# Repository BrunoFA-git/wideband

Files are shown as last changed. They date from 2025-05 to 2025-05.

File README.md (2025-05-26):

 

# gerEFI Wideband Controller

[User Documentation](https://gerefi.com/s/wb)

## Building Firmware

The `firmware/boards` directory contains configuration for each board this firmware supports.

For the standalone board and the module built in to gerEFI Hellen boards, `f0_module` is the correct target.  Use the `build_wideband.sh` script to build and package the wideband firmware: both a bin including the bootloader, and a header file consumed by gerEFI that contains no bootloader, to be uploaded over CAN (via the aforementioned bootloader).

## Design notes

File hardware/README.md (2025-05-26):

## `board_module`

Wideband O2 sensor controller on a postage stamp. Contains all the analog and digital control logic to handle a Bosch LSU 4.2, 4.9, or ADV sensor.

Intended to either be mounted on an ECU as a module, or on `board_carrier` to run standalone.

## `board_carrier`

Stacks under `board_module`, has 5v regulator, CAN tranceiver, etc so that the module can exist standlone.

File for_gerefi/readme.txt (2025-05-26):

The file wideband_image.h is generated for use by gerEFI to be able to beam firmware updates to attached wideband controllers.

Use ``cd firmware/boards/f0_module ; ./build_wideband.sh`` to build a fresh version.

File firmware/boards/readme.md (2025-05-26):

Both single-channel and dual-channel F103 boards live at https://github.com/gerefi/gerefi-hardware

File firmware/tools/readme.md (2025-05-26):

* wideband.bin
 initial firmware with botb OpenBLT and current wideband firmware.

* wideband_update.srec
 gerEFI wideband firmware for OpenBLT-via-CAN or OpenBLT-via-uart update methods.

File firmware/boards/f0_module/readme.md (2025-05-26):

Firmware for reference https://github.com/mck1117/wideband/tree/master/board_module F0 hardware.

Also the firmware for https://github.com/BrunoFA-git/hellen-one/tree/master/modules/wbo.

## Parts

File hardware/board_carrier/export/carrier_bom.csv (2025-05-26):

Comment | Designator | Footprint | LCSC
1u | C1,C2,C3 | Capacitor_SMD:C_0603_1608Metric | C15849
47p | C4,C5 | Capacitor_SMD:C_0402_1005Metric | C1567
D_TVS | D1 | Diode_SMD:D_SMC | C133648
D_Schottky | D2 | Diode_SMD:D_SMA | C8678
220 | R1 | Resistor_SMD:R_0603_1608Metric | C22962
470 | R2 | Resistor_SMD:R_0603_1608Metric | C23179
TJA1051T-3 | U1 | Package_SO:SOIC-8_3.9x4.9mm_P1.27mm | C38695
LM78M05_TO252 | U2 | Package_TO_SOT_SMD:TO-252-2 | C58069

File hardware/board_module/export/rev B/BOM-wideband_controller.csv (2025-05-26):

Comment | Designator | Footprint | LCSC
BTS3028 | Q1 | TO-252-2 | C112639
1k | R1,R13,R18,R2,R25,R26,R27,R30 | R_0402_1005Metric | C11702
100n | C11,C12,C13,C14,C16,C2,C5,C8,C9 | C_0402_1005Metric | C1525
33n | C3 | C_0402_1005Metric | C1585
4.7u | C10 | C_0603_1608Metric | C19666
RED | D1,D4 | LED_0603_1608Metric | C2286
61.9 | R10 | R_0603_1608Metric | C23092
62k | R14 | R_0603_1608Metric | C23221
10 | R9 | R_0402_1005Metric | C25077
47 | R8 | R_0402_1005Metric | C25118
100k | R15,R17,R20 | R_0402_1005Metric | C25741
10k | R11,R12,R21,R29,R3,R33,R34,R4 | R_0402_1005Metric | C25744
22k | R6 | R_0402_1005Metric | C25768
27k | R5,R7 | R_0402_1005Metric | C25771
47k | R19 | R_0402_1005Metric | C25792
3.3k | R24 | R_0402_1005Metric | C25890
6.8k | R16 | R_0402_1005Metric | C25917
AD8628 | U5 | TSOT-23-5 | C29309
REF3033 | U3 | SOT-23 | C36658
68k | R31,R32 | R_0402_1005Metric | C36871
MCP6004 | U1 | TSSOP-14_4.4x5mm_P0.65mm | C50282
1u | C1,C17,C4,C6,C7 | C_0402_1005Metric | C52923
XC6206P332MR | U9 | SOT-23 | C5446
STM32F042K6Tx | U2 | LQFP-32_7x7mm_P0.8mm | C69216
BLUE | D3 | LED_0603_1608Metric | C72041
GREEN | D2 | LED_0603_1608Metric | C72043
Conn_01x08 | J3 | PinHeader_1x08_P2.54mm_Vertical
Conn_01x08 | J1 | PinHeader_1x08_P2.54mm_Vertical

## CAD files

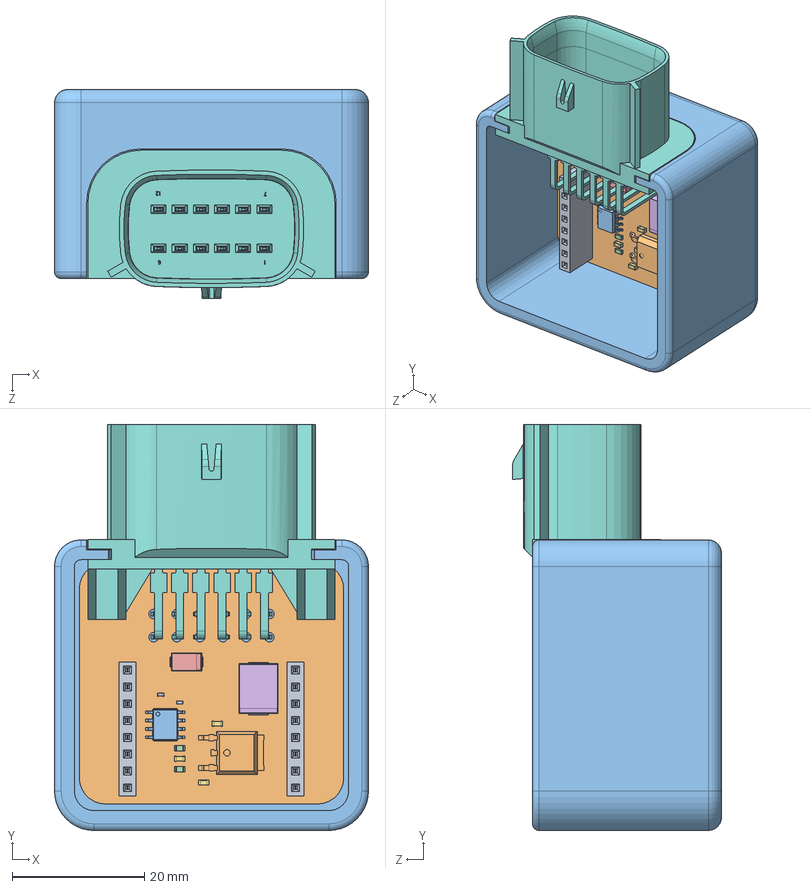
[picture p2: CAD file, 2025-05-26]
case/board_carrier.step.SLDASM
47.5 x 61.4 x 31.6 mm
SOLID.step x 2
SOLID-0.step
SOLID-1.step
SOLID-2.step x 2
SOLID-3.step
SOLID-4.step
SOLID-5.step x 3
COMPOUND.step
SOLID-6.step x 2
COMPOUND-7.step
Part13^board_carrier.step

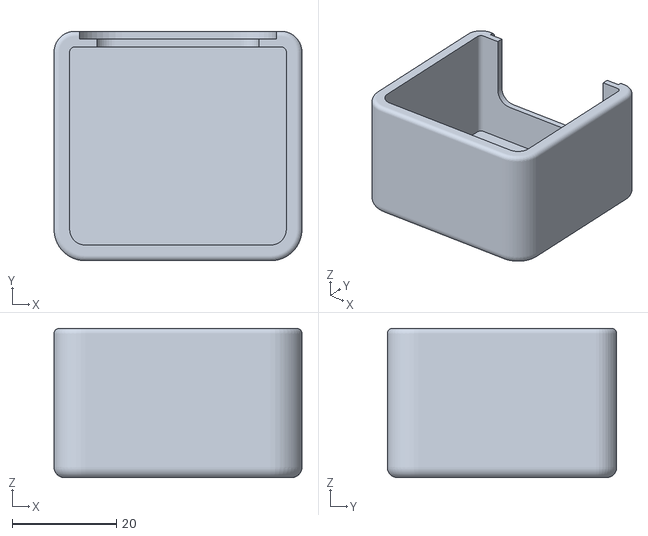
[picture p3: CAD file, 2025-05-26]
case/case.STL
47.5 x 44.0 x 28.6

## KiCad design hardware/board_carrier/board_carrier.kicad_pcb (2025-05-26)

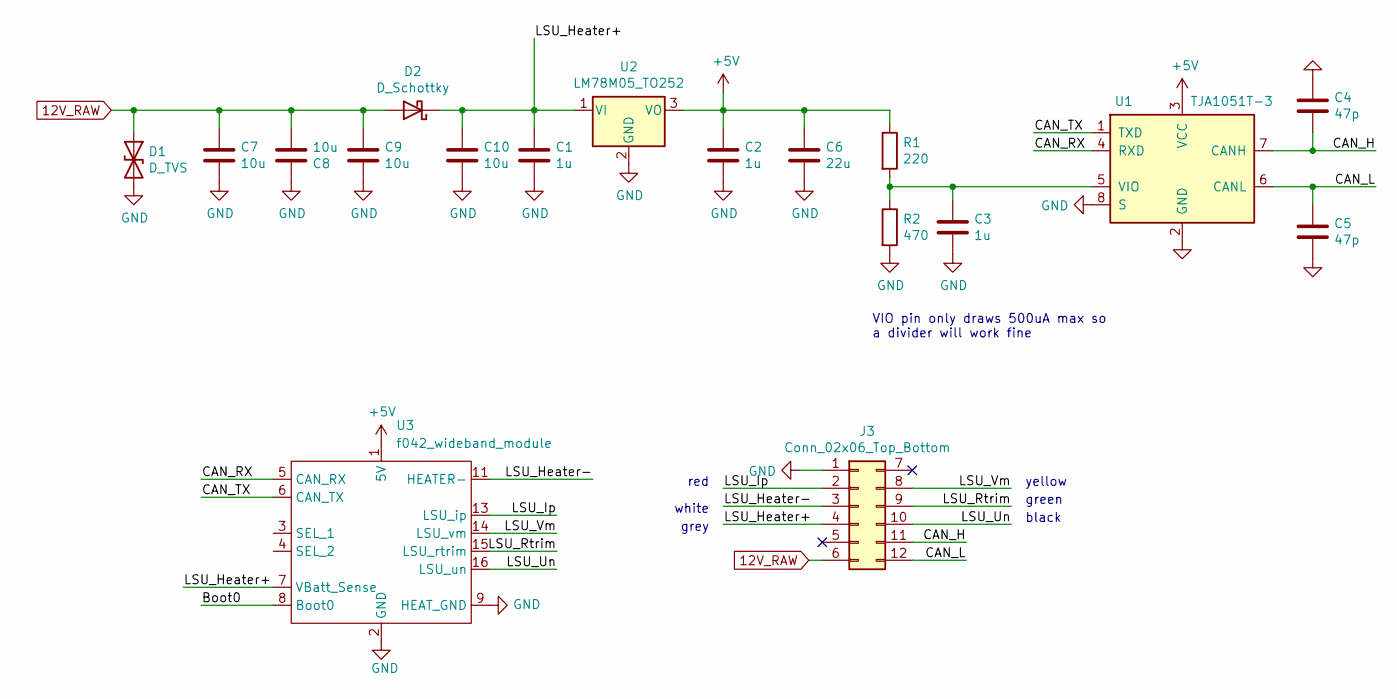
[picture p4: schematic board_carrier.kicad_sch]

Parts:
C1, C2, C3: 1u; C_0603_1608Metric; LCSC C15849
C4, C5: 47p; C_0402_1005Metric; LCSC C1567
C6: 22u; C_0805_2012Metric; LCSC C45783
C7, C8, C9, C10: 10u; C_1206_3216Metric; LCSC C13585
D1: D_TVS; D_SMC; LCSC C151279
D2: D_Schottky; D_SMA; LCSC C22452
J3: Conn_02x06_Top_Bottom; mx120g-12
R1: 220; R_0603_1608Metric; LCSC C22962
R2: 470; R_0603_1608Metric; LCSC C23179
U1: TJA1051T-3; SOIC-8_3.9x4.9mm_P1.27mm; LCSC C38695
U2: LM78M05_TO252; TO-252-2; LCSC C58069
U3: f042_wideband_module

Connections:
12V_RAW: C7.1, C8.2, C9.1, D1.1 (A1), D2.2 (A), J3.6
+5V: C2.1, C6.1, R1.1, U1.3 (VCC), U2.3 (VO), U3.1 (5V)
/Boot0: U3.8 (Boot0)
/CAN_H: C4.2, J3.11, U1.7 (CANH)
/CAN_L: C5.1, J3.12, U1.6 (CANL)
/CAN_RX: U1.4 (RXD), U3.5 (CAN_RX)
/CAN_TX: U1.1 (TXD), U3.6 (CAN_TX)
/LSU_Heater+: C1.1, C10.1, D2.1 (K), J3.4, U2.1 (VI), U3.7 (VBatt_Sense)
/LSU_Heater-: J3.3, U3.11 (HEATER-), U3.12 (HEATER-)
/LSU_Ip: J3.2, U3.13 (LSU_ip)
/LSU_Rtrim: J3.9, U3.15 (LSU_rtrim)
/LSU_Un: J3.10, U3.16 (LSU_un)
/LSU_Vm: J3.8, U3.14 (LSU_vm)
GND: C1.2, C2.2, C3.2, C4.1, C5.2, C6.2, C7.2, C8.1, C9.2, C10.2, D1.2 (A2), J3.1, R2.2, U1.2 (GND), U1.8 (S), U2.2 (GND), U3.2 (GND), U3.9 (HEAT_GND), U3.10 (HEAT_GND2)
unnamed: C3.1, R1.2, R2.1, U1.5 (VIO)

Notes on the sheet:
yellow
green
red
black
white
VIO pin only draws 500uA max so a divider will work fine
grey

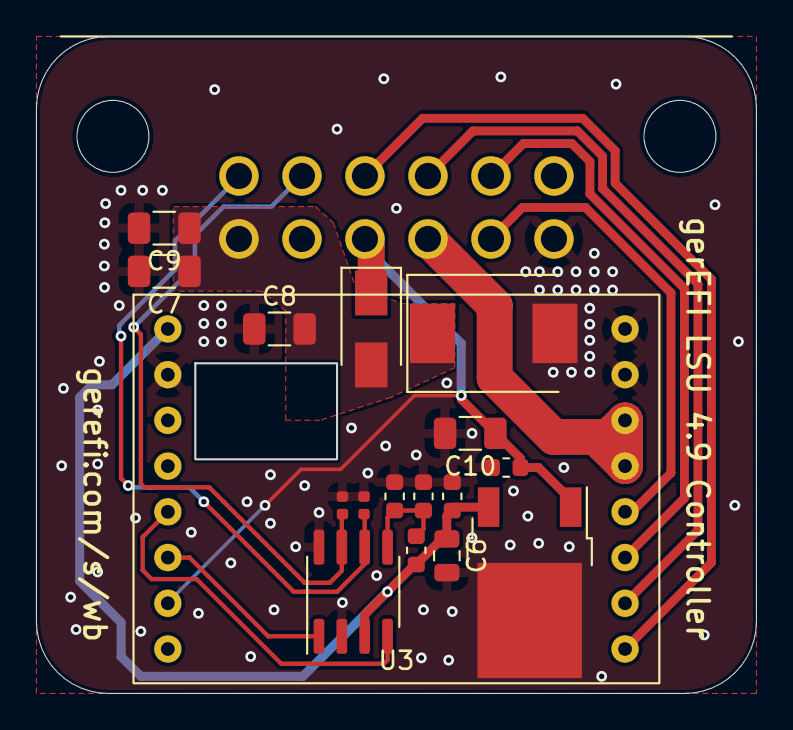
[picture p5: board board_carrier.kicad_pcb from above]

Board: 2 copper layers, 40.0 x 36.5 mm, 18 parts (0 on the bottom side), 14 nets.

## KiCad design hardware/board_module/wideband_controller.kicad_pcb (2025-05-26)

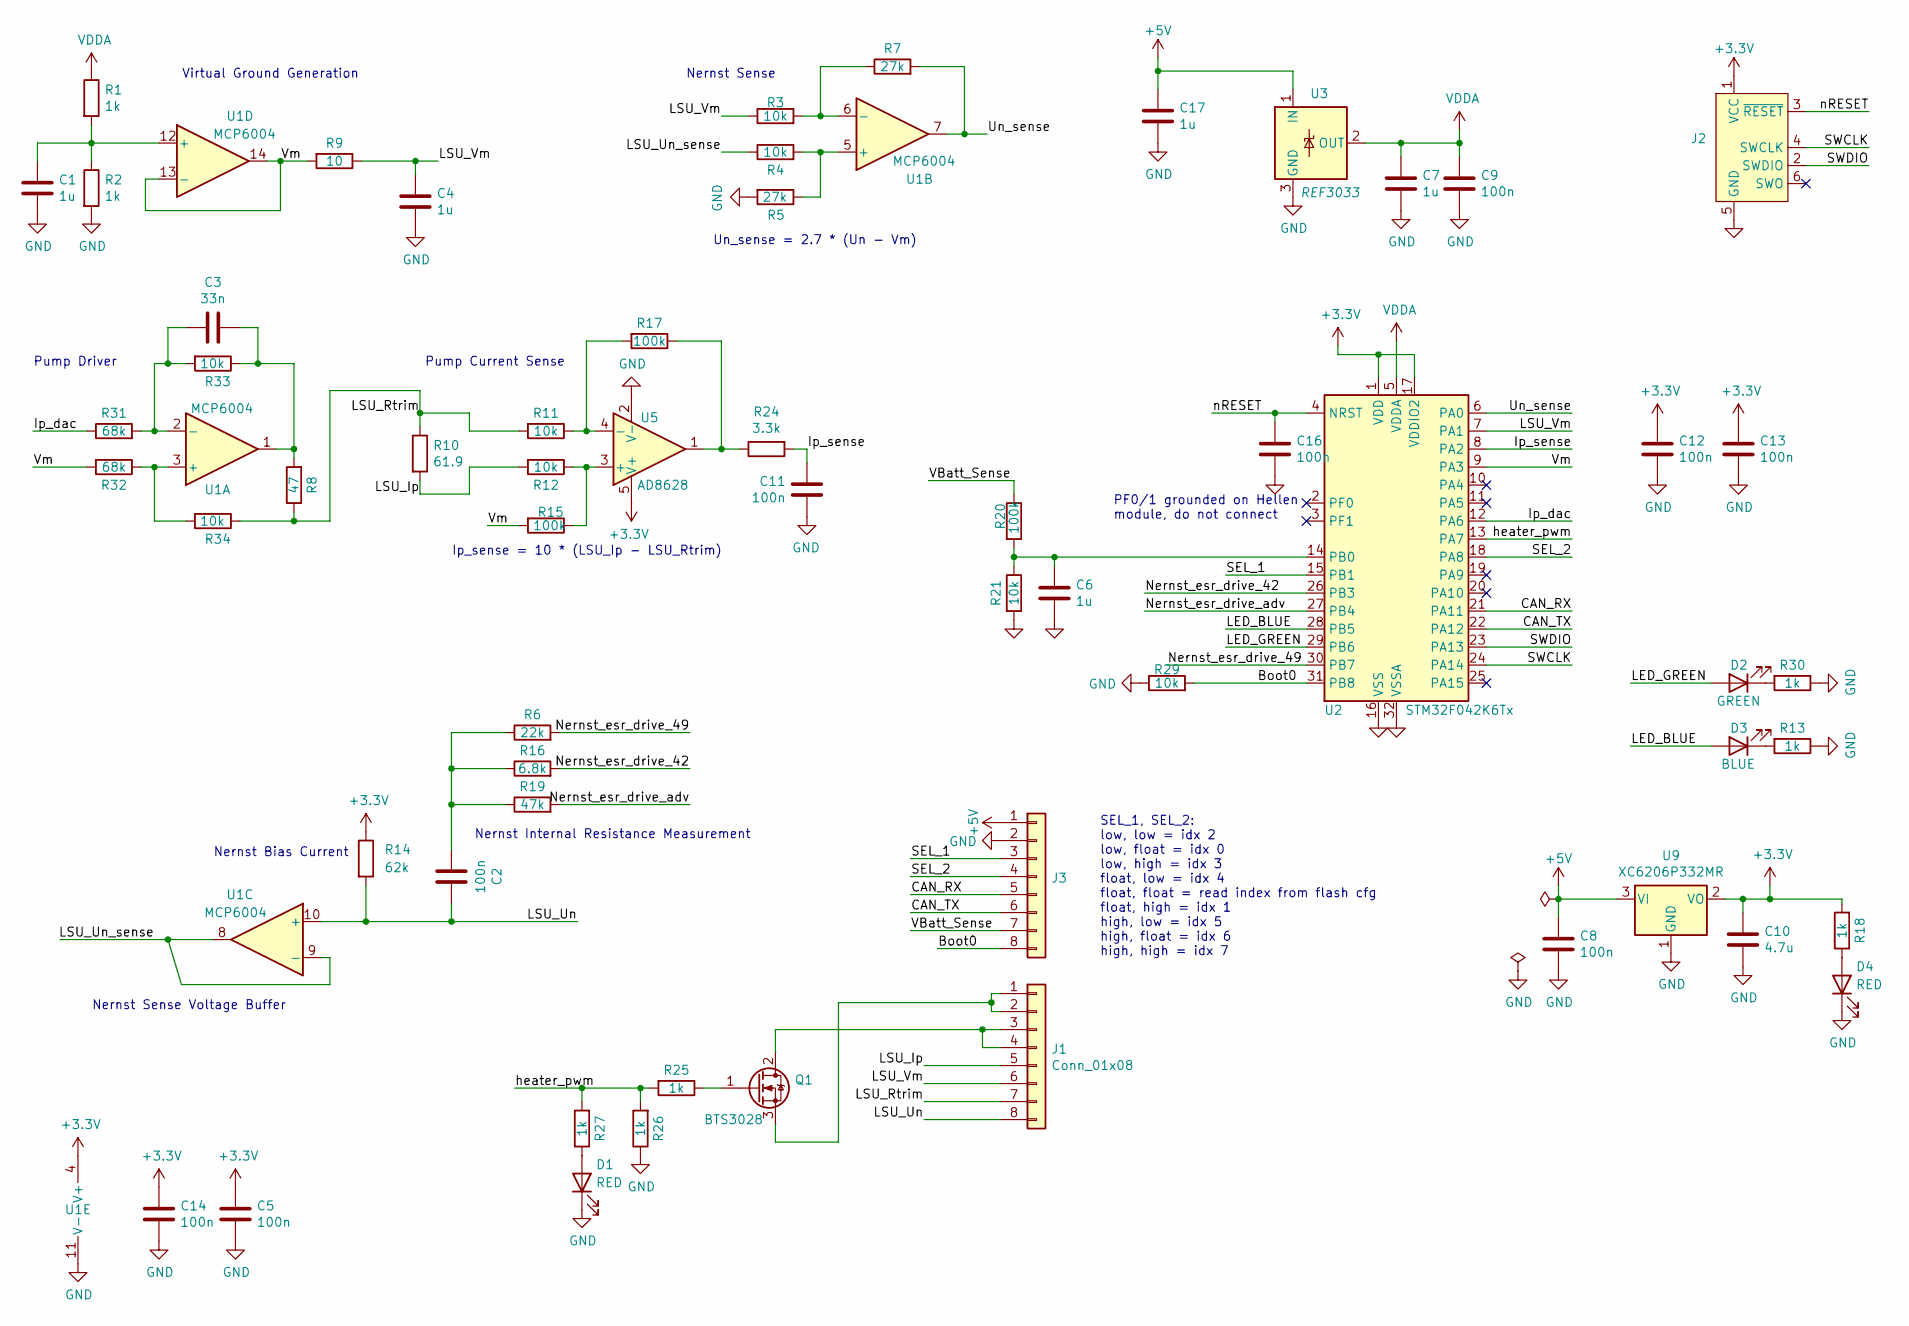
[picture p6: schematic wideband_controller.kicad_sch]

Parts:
C1, C4, C6, C7, C17: 1u; C_0402_1005Metric; LCSC C52923
C2, C5, C8, C9, C11, C12, C13, C14, C16: 100n; C_0402_1005Metric; LCSC C1525
C3: 33n; C_0402_1005Metric; LCSC C1585
C10: 4.7u; C_0603_1608Metric; LCSC C19666
D1, D4: RED; LED_0603_1608Metric; LCSC C2286
D2: GREEN; LED_0603_1608Metric; LCSC C72043
D3: BLUE; LED_0603_1608Metric; LCSC C72041
J1, J3: Conn_01x08; PinHeader_1x08_P2.54mm_Vertical
J2: Conn_ARM_SWD_TagConnect_TC2030; Tag-Connect_TC2030-IDC-NL_2x03_P1.27mm_Vertical
Q1: BTS3028; TO-252-2; LCSC C112639
R1, R2, R13, R18, R25, R26, R27, R30: 1k; R_0402_1005Metric; LCSC C11702
R3, R4, R11, R12, R21, R29, R33, R34: 10k; R_0402_1005Metric; LCSC C25744
R5, R7: 27k; R_0402_1005Metric; LCSC C25771
R6: 22k; R_0402_1005Metric; LCSC C25768
R8: 47; R_0402_1005Metric; LCSC C25118
R9: 10; R_0402_1005Metric; LCSC C25077
R10: 61.9; R_0603_1608Metric; LCSC C23092
R14: 62k; R_0603_1608Metric; LCSC C23221
R15, R17, R20: 100k; R_0402_1005Metric; LCSC C25741
R16: 6.8k; R_0402_1005Metric; LCSC C25917
R19: 47k; R_0402_1005Metric; LCSC C25792
R24: 3.3k; R_0402_1005Metric; LCSC C25890
R31, R32: 68k; R_0402_1005Metric; LCSC C36871
U1: MCP6004; TSSOP-14_4.4x5mm_P0.65mm; LCSC C50282
U2: STM32F042K6Tx; LQFP-32_7x7mm_P0.8mm; LCSC C69216
U3: REF3033; SOT-23; LCSC C36658
U5: AD8628; TSOT-23-5; LCSC C29309
U9: XC6206P332MR; SOT-23; LCSC C5446

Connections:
+3V3: C5.1, C10.1, C12.1, C13.1, C14.1, J2.1 (VCC), R14.1, R18.2, U1.4 (V+), U2.1 (VDD), U2.17 (VDDIO2), U5.5 (V+), U9.2 (VO)
+5V: C8.1, C17.1, J3.1, U3.1 (IN), U9.3 (VI)
/Boot0: J3.8, R29.2, U2.31 (PB8)
/CAN_RX: J3.5, U2.21 (PA11)
/CAN_TX: J3.6, U2.22 (PA12)
/Ip_dac: R31.1, U2.12 (PA6)
/Ip_sense: C11.1, R24.2, U2.8 (PA2)
/LED_BLUE: D3.2 (A), U2.28 (PB5)
/LED_GREEN: D2.2 (A), U2.29 (PB6)
/LSU_Ip: J1.5, R10.2, R12.2
/LSU_Rtrim: J1.7, R8.1, R10.1, R11.2, R34.1
/LSU_Un: C2.1, J1.8, R14.2, U1.10 (+)
/LSU_Un_sense: R4.1, U1.8, U1.9 (-)
/LSU_Vm: C4.1, J1.6, R3.1, R9.1, U2.7 (PA1)
/Nernst_esr_drive_42: R16.2, U2.26 (PB3)
/Nernst_esr_drive_49: R6.2, U2.30 (PB7)
/Nernst_esr_drive_adv: R19.2, U2.27 (PB4)
/SEL_1: J3.3, U2.15 (PB1)
/SEL_2: J3.4, U2.18 (PA8)
/SWCLK: J2.4 (SWCLK), U2.24 (PA14)
/SWDIO: J2.2 (SWDIO), U2.23 (PA13)
/Un_sense: R7.2, U1.7, U2.6 (PA0)
/VBatt_Sense: J3.7, R20.1
/Vm: R9.2, R15.2, R32.2, U1.13 (-), U1.14, U2.9 (PA3)
/heater_pwm: R25.2, R26.2, R27.2, U2.13 (PA7)
/nRESET: C16.1, J2.3 (~RESET), U2.4 (NRST)
GND: C1.2, C4.2, C5.2, C6.2, C7.2, C8.2, C9.2, C10.2, C11.2, C12.2, C13.2, C14.2, C16.2, C17.2, D1.1 (K), D4.1 (K), J2.5 (GND), J3.2, R2.2, R5.2, R13.1, R21.2, R26.1, R29.1, R30.1, U1.11 (V-), U2.16 (VSS), U2.32 (VSSA), U3.3 (GND), U5.2 (V-), U9.1 (GND)
unnamed: C1.1, R1.2, R2.1, U1.12 (+)
unnamed: C2.2, R6.1, R16.1, R19.1
unnamed: C3.1, R8.2, R33.1, U1.1
unnamed: C3.2, R31.2, R33.2, U1.2 (-)
unnamed: C6.1, R20.2, R21.1, U2.14 (PB0)
unnamed: D1.2 (A), R27.1
unnamed: D2.1 (K), R30.2
unnamed: D3.1 (K), R13.2
unnamed: D4.2 (A), R18.1
unnamed: J1.1, J1.2, Q1.3 (S)
unnamed: J1.3, J1.4, Q1.2 (D)
unnamed: Q1.1 (G), R25.1
unnamed: R3.2, R7.1, U1.6 (-)
unnamed: R4.2, R5.1, U1.5 (+)
unnamed: R11.1, R17.2, U5.4 (-)
unnamed: R12.1, R15.1, U5.3 (+)
unnamed: R17.1, R24.1, U5.1
unnamed: R32.1, R34.2, U1.3 (+)
VDDA: C7.1, C9.1, R1.1, U2.5 (VDDA), U3.2 (OUT)

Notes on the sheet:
Un_sense = 2.7 * (Un - Vm)
Nernst Internal Resistance Measurement
Pump Driver
Nernst Sense Voltage Buffer
PF0/1 grounded on Hellen module, do not connect
Nernst Bias Current
Ip_sense = 10 * (LSU_Ip - LSU_Rtrim)
Virtual Ground Generation
Nernst Sense
Pump Current Sense
SEL_1, SEL_2: low, low = idx 2 low, float = idx 0 low, high = idx 3 float, low = idx 4 float, float = read index from flash cfg float, high = idx 1 high, low = idx 5 high, float = idx 6 high, high = idx 7

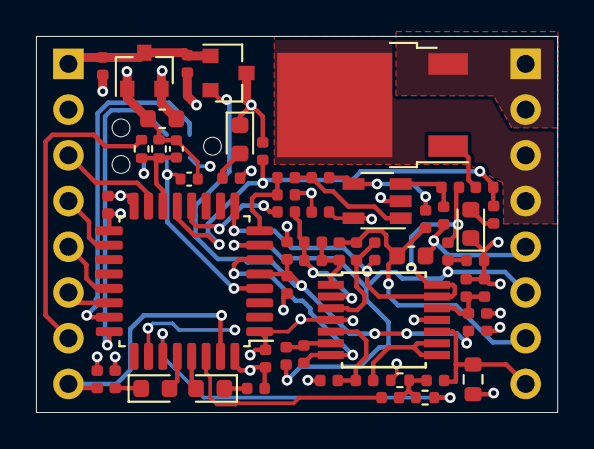
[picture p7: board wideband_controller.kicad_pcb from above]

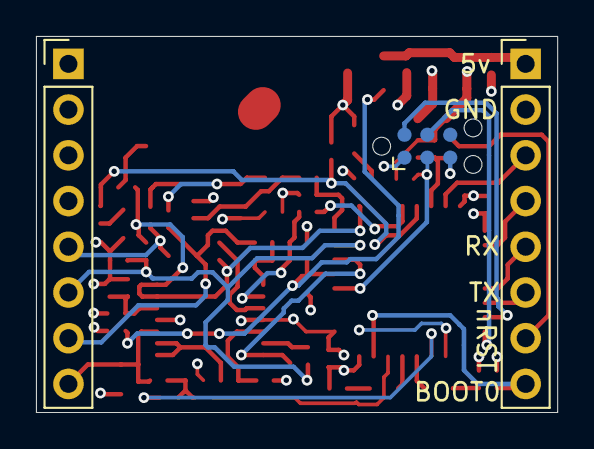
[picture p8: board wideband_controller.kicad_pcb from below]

Board: 4 copper layers, 29.0 x 20.9 mm, 60 parts (3 on the bottom side), 46 nets.

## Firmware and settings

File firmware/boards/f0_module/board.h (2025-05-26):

/*
    ChibiOS - Copyright (C) 2006..2020 Giovanni Di Sirio

    Licensed under the Apache License, Version 2.0 (the "License");
    you may not use this file except in compliance with the License.
    You may obtain a copy of the License at

        http://www.apache.org/licenses/LICENSE-2.0

    Unless required by applicable law or agreed to in writing, software
    distributed under the License is distributed on an "AS IS" BASIS,
    WITHOUT WARRANTIES OR CONDITIONS OF ANY KIND, either express or implied.
    See the License for the specific language governing permissions and
    limitations under the License.
*/

/*
 * This file has been automatically generated using ChibiStudio board
 * generator plugin. Do not edit manually.
 */

#ifndef BOARD_H
#define BOARD_H

/*===========================================================================*/
/* Driver constants.                                                         */
/*===========================================================================*/


/*
 * Board identifier.
 */
#define BOARD_NAME                  "gerEfi Wideband Controller"

/*
 * Board oscillators-related settings.
 * NOTE: LSE not fitted.
 * NOTE: HSE not fitted.
 */
#if !defined(STM32_LSECLK)
#define STM32_LSECLK                0U
#endif

#define STM32_LSEDRV                (3U << 3U)

#if !defined(STM32_HSECLK)
#define STM32_HSECLK                0U
#endif

/*
 * MCU type as defined in the ST header.
 */
#define STM32F042x6

/*
 * IO pins assignments.
 */
#define GPIOA_PIN0                  0U
#define GPIOA_PIN1                  1U
#define GPIOA_PIN2                  2U
#define GPIOA_PIN3                  3U
#define GPIOA_PIN4                  4U
#define GPIOA_PIN5                  5U
#define GPIOA_PIN6                  6U
#define GPIOA_PIN7                  7U
#define GPIOA_PIN8                  8U
#define GPIOA_PIN9                  9U
#define GPIOA_PIN10                 10U
#define GPIOA_PIN11                 11U
#define GPIOA_PIN12                 12U
#define GPIOA_SWDIO                 13U
#define GPIOA_SWCLK                 14U
#define GPIOA_PIN15                 15U

#define GPIOB_PIN0                  0U
#define GPIOB_PIN1                  1U
#define GPIOB_PIN2                  2U
#define GPIOB_PIN3                  3U
#define GPIOB_PIN4                  4U
#define GPIOB_PIN5                  5U
#define GPIOB_PIN6                  6U
#define GPIOB_PIN7                  7U
#define GPIOB_PIN8                  8U
#define GPIOB_PIN9                  9U
#define GPIOB_PIN10                 10U
#define GPIOB_PIN11                 11U
#define GPIOB_PIN12                 12U
#define GPIOB_PIN13                 13U
#define GPIOB_PIN14                 14U
#define GPIOB_PIN15                 15U

#define GPIOC_PIN0                  0U
#define GPIOC_PIN1                  1U
#define GPIOC_PIN2                  2U
#define GPIOC_PIN3                  3U
#define GPIOC_PIN4                  4U
#define GPIOC_PIN5                  5U
#define GPIOC_PIN6                  6U
#define GPIOC_PIN7                  7U
#define GPIOC_PIN8                  8U
#define GPIOC_PIN9                  9U
#define GPIOC_PIN10                 10U
#define GPIOC_PIN11                 11U
#define GPIOC_PIN12                 12U
#define GPIOC_PIN13                 13U
#define GPIOC_PIN14                 14U
#define GPIOC_PIN15                 15U

#define GPIOF_PIN0                0U
#define GPIOF_PIN1                1U
#define GPIOF_PIN2                  2U
#define GPIOF_PIN3                  3U
#define GPIOF_PIN4                  4U
#define GPIOF_PIN5                  5U
#define GPIOF_PIN6                  6U
#define GPIOF_PIN7                  7U
#define GPIOF_PIN8                  8U
#define GPIOF_PIN9                  9U
#define GPIOF_PIN10                 10U
#define GPIOF_PIN11                 11U
#define GPIOF_PIN12                 12U
#define GPIOF_PIN13                 13U
#define GPIOF_PIN14                 14U
#define GPIOF_PIN15                 15U

/*===========================================================================*/
/* Driver pre-compile time settings.                                         */
/*===========================================================================*/

/*===========================================================================*/
/* Derived constants and error checks.                                       */
/*===========================================================================*/

/*===========================================================================*/
/* Driver data structures and types.                                         */
/*===========================================================================*/

/*===========================================================================*/
/* Driver macros.                                                            */
/*===========================================================================*/
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

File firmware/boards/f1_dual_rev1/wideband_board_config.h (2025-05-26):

#pragma once

// TS settings
#define TS_SIGNATURE "gerEFI 2023.05.10.wideband_dual"

// This board implements two channels
#define AFR_CHANNELS 2
#define EGT_CHANNELS 2

// Fundamental board constants
#define VCC_VOLTS (3.3f)
#define HALF_VCC (VCC_VOLTS / 2)
#define ADC_MAX_COUNT (4095)
#define ADC_OVERSAMPLE 16

// Algo settings
// TODO: move to settings
#define HEATER_FAST_HEATING_THRESHOLD_T		550

// *******************************
//    Nernst voltage & ESR sense
// *******************************
#define NERNST_INPUT_GAIN (3.15f)
#define NERNST_INPUT_OFFSET (0.247)

// *******************************
//        Battery Sensing
// *******************************
// 100K + 10K divider
#define BATTERY_INPUT_DIVIDER (10.0 / (10.0 + 100.0))

// *******************************
//     Heater low side Sensing
// *******************************
// 100K + 10K divider
#define HEATER_INPUT_DIVIDER (10.0 / (10.0 + 100.0))
#define HEATER_FILTER_ALPHA (0.1f)

// *******************************
//        Vm output Sensing
// *******************************
// 100K + 10K divider
#define VM_INPUT_DIVIDER (10.0 / (10.0 + 100.0))

// *******************************
//    Nernst voltage & ESR sense
// *******************************
#define VM_RESISTOR_VALUE (0)

// *******************************
//          AUX outputs
// *******************************
// OpAmp with 82K + 160K
#define AUXOUT_GAIN         ((82.0 + 160.0) / 160.0)

// *******************************
// With heater constantly on we
// are not able to measure Vbatt
// through Heater-
// *******************************
// TODO: remove!
#define HEATER_MAX_DUTY		(0.85)

// *******************************
//   TunerStudio Primary Port - Routed to BlueTooth
// *******************************
#define TS_PRIMARY_SERIAL_PORT	SD3
#define TS_PRIMARY_BAUDRATE		115200

#if 1
// *******************************
//   TunerStudio Secondary Port - J3 connector (2x2)
// *******************************
#define TS_SECONDARY_SERIAL_PORT	SD1
#define TS_SECONDARY_BAUDRATE		115200
#else
// *******************************
//   Debug serial device
// *******************************
#define DEBUG_SERIAL_PORT			SD1
#define DEBUG_SERIAL_BAUDRATE		115200
#endif

// *******************************
//   MAX31855 spi port
// *******************************
#define EGT_SPI_DRIVER			(&SPID3)

// Serial connection over BT module
// enable BT module setup attempt
#define BT_SERIAL_OVER_JDY33	TRUE
#define BT_BROADCAST_NAME		"GerEFI WBO x2"

// *******************************
//   Indication: per channel status LED + communication LED
// *******************************
#define ADVANCED_INDICATION
